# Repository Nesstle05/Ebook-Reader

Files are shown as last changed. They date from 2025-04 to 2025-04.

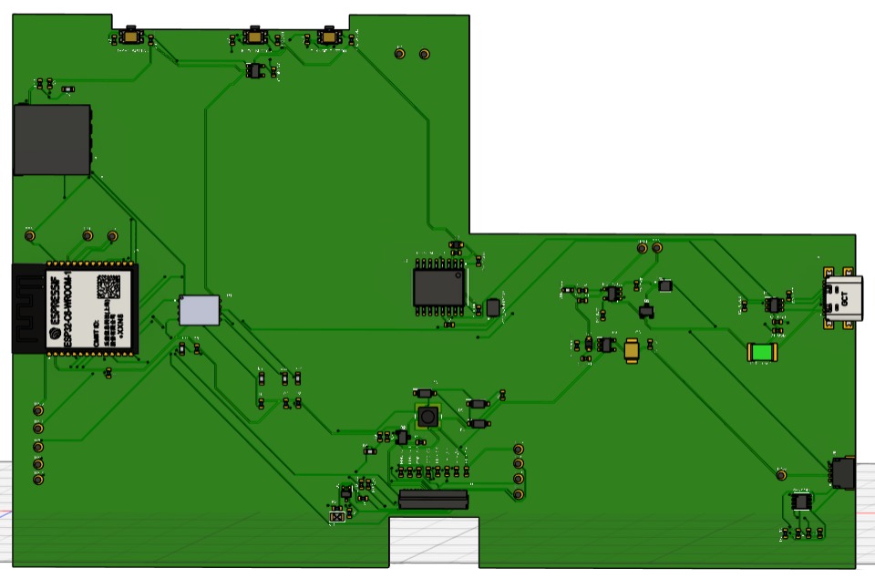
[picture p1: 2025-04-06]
Images/pcb3D.jpg

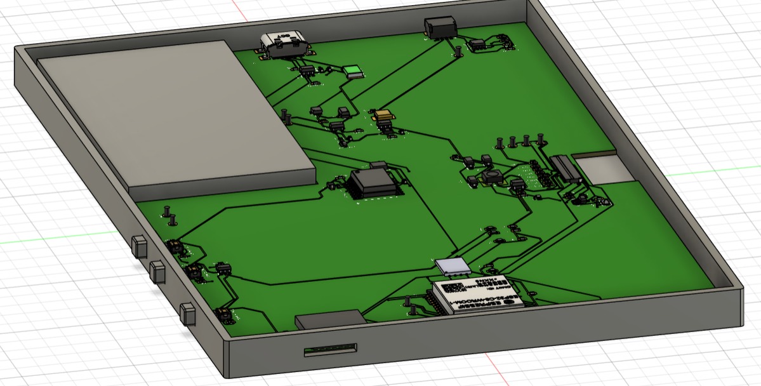
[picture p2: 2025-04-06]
Images/openbook_enclosure2.jpg

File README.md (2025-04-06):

# Ebook-Reader

### Pasii de implementare
* Am creat schematicul 2D.
* Am creat PCB-ul, am intampinat niste erori:
    * **Via(hole) error** la componenta USB: am modificat footprint-ul componentei.
    * **Wire to wire error**: am rutat firele manual
* Am atribuit fiecarei componente din library cate un model 3D, si am creat placa 3d (*Push to 3D*)
* Am creat modelele pentru Display si Baterie dupa specificatiile din datasheeturi

## Diagrama bloc


## Utilizarea Pinilor ESP32-C6

Următorul tabel detaliază pinii GPIO specifici utilizați pe modulul ESP32-C6-WROOM-1 și funcțiile acestora în cadrul acestui proiect:

| Pin ESP32-C6 | Funcție | Component(e) Conectat(e) | Interfață/Motiv |
| :--- | :--- | :--- | :--- |
| GPIO0 | Selecție Boot / Intrare Buton | SW_BOOT (Buton Boot), R_BOOT | Pin standard pentru selecția modului boot; Intrare utilizator |
| GPIO1 | Ceas I2C | U4 (MAX17048), U3 (DS3231), SENSOR2 (BME688), J5 (Qwiic) | Magistrală I2C comună (SCL) pentru multipli senzori/CI |
| GPIO2 | Date I2C | U4 (MAX17048), U3 (DS3231), SENSOR2 (BME688), J5 (Qwiic) | Magistrală I2C comună (SDA) pentru multipli senzori/CI |
| GPIO3 | Selecție Cip E-Paper | J1 (Header EPD) | Selecție Cip SPI (CS) pentru Afișajul E-Paper |
| GPIO4 | Dată/Comandă E-Paper | J1 (Header EPD) | Control Dată/Comandă (DC) pentru Afișajul E-Paper |
| GPIO5 | Reset E-Paper | J1 (Header EPD) | Semnal Reset (RST) pentru Afișajul E-Paper |
| GPIO6 | Stare Ocupat E-Paper | J1 (Header EPD) | Semnal intrare Ocupat (Busy) de la Afișajul E-Paper |
| GPIO7 | Hold Flash Extern | U1 (W25Q64JV), TP17 | Semnal SPI Hold (/HOLD) pentru memoria flash externă |
| GPIO8 | Dată 0 Card SD | J2 (Slot Card SD), TP6 | Linie Date SDIO 0 / SPI MISO |
| GPIO9 | Dată 1 Card SD | J2 (Slot Card SD), TP7 | Linie Date SDIO 1 |
| GPIO10 | Comandă Card SD | J2 (Slot Card SD), TP5 | Linie Comandă SDIO / SPI MOSI |
| GPIO11 | Ceas Card SD | J2 (Slot Card SD), TP4 | Linie Ceas SDIO / SPI SCK |
| GPIO12 | Protecție Scriere Flash Extern | U1 (W25Q64JV), TP16 | Semnal SPI Protecție Scriere (/WP) pentru flash extern |
| GPIO13 | MISO Flash Extern | U1 (W25Q64JV), TP15 | SPI Master In Slave Out (MISO) pentru flash extern |
| GPIO14 | MOSI Flash Extern | U1 (W25Q64JV), TP14 | SPI Master Out Slave In (MOSI) pentru flash extern |
| GPIO15 | Selecție Cip Flash Extern | U1 (W25Q64JV), TP13 | Selecție Cip SPI (/CS) pentru memoria flash externă |
| GPIO16 | UART TXD | TP12 | Date Transmise UART pentru depanare/programare |
| GPIO17 | UART RXD | TP11 | Date Recepționate UART pentru depanare/programare |
| GPIO18 | Ceas Flash Extern | U1 (W25Q64JV), TP3 | Ceas SPI (SCK) pentru memoria flash externă |
| GPIO19 | Dată 2 Card SD | J2 (Slot Card SD), TP8 | Linie Date SDIO 2 |
| GPIO20 | Dată 3 Card SD / Detectare Card | J2 (Slot Card SD), TP9 | Linie Date SDIO 3 / Intrare Detectare Card |
| GPIO21 | Intrare Buton Change | SW_CHANGE (Buton Change) | Intrare de Uz General pentru interacțiune utilizator |
| USB_D- | Date Negative USB | J4 (Conector USB-C) | Semnal Nativ USB D- |
| USB_D+ | Date Pozitive USB | J4 (Conector USB-C) | Semnal Nativ USB D+ |
| EN | Activare Sistem / Reset | U5 (BD5229G), SW_RESET (Buton Reset) | Activare Cip, controlat de supervizor tensiune/buton |

## Energy management

| Component | Power Supply (V) | Estimated Current (mA) | Estimated Power (W) | Notes |
|---|---|---|---|---|
| ESP32-C6-WROOM-1-N8 | 3.3 | 150 (average) | 0.5 | Active mode; varies significantly based on usage. |
| SD Card Module | 3.3 | 10 (average) | 0.033 | Intermittent read/write operations. |
| E-Paper Display | 3.3 | 1(average) | 0.0033 | Power used only during updates, very low average. |
| RTC Module - DS3231SN | 3.3 | 1 | 0.0033 | |
| LiPo Fuel Gauger (MAX17048) | 3.3 | 0.05 | 0.000165 | Very low power consumption. |
| BME688 (Environmental Sensor) | 3.3 | 1 (average) | 0.0033 | Intermittent readings. |
| NORFlash64MB (External Flash)| 3.3 | 2 (average) | 0.0066 | Intermittent read/write operations. |
| LDO Voltage Regulator | 5 (input) / 3.3 (output) | Variable | Variable | Efficiency depends on load; quiescent current is very low. |
| USB-C Connector + ESD | 5 (input) | Variable | Variable | Power depends on charging current; ESD protection negligible. |
| Reset/Boot Buttons | N/A | Negligible | Negligible | |
| **Total (Approximate)** | | 150-200 | **~0.55** | This is a rough estimate; actual power depends on duty cycles and usage. |

## Bill Of Materials (BOM)
| Componenta | Achizitie | Datasheet |
| --- | --- | --- |
| PFMF.050.1 | [Cumpara](https://ro.mouser.com/ProductDetail/Schurter/PFMF.050.2?qs=1auRipcfynCums5v1iucSA%3D%3D) |  [Datasheet](https://ro.mouser.com/datasheet/2/358/typ_PFMF-1275918.pdf) |
| USB4110-GF-A | [Cumpara](https://ro.mouser.com/ProductDetail/GCT/USB4110-GF-A?qs=KUoIvG%2F9IlYiZvIXQjyJeA%3D%3D) | [Datasheet](https://ro.mouser.com/datasheet/2/837/GCT_USB4110_Product_Drawing___20k_cycles-3455479.pdf) |
| USBLC6-2SC6Y | [Cumpara](https://ro.mouser.com/ProductDetail/STMicroelectronics/USBLC6-2SC6Y?qs=gNDSiZmRJS%2FOgDexvXkdow%3D%3D) | [Datasheet](https://ro.mouser.com/datasheet/2/389/usblc6_2sc6y-1852505.pdf) |
| SD0805S020S1R0 | [Cumpara](https://ro.mouser.com/ProductDetail/KYOCERA-AVX/SD0805S020S1R0?qs=jCA%252BPfw4LHbpkAoSnwrdjw%3D%3D) | [Datasheet](https://ro.mouser.com/datasheet/2/40/schottky-3165252.pdf) |
| DMG2305UX-7 | [Cumpara](https://ro.mouser.com/ProductDetail/Diodes-Incorporated/DMG2305UX-7?qs=L1DZKBg7t5F%2FNBHrjfxC%252Bg%3D%3D) | [Datasheet](https://www.diodes.com/assets/Datasheets/DMG2305UX.pdf) |
| XC6220A331MR-G | [Cumpara](https://ro.mouser.com/ProductDetail/Torex-Semiconductor/XC6220A331MR-G?qs=AsjdqWjXhJ8ZSWznL1J0gg%3D%3D) | [Datasheet](https://ro.mouser.com/datasheet/2/760/xc6220-3371556.pdf) |
| Condensator 100 uF TANT | [Cumpara](https://ro.mouser.com/ProductDetail/KYOCERA-AVX/TAJW107M010RNJ?qs=Wtp%252Bf%2FAeVqIH8v1VxV%252B1Rg%3D%3D) | [Datasheet](https://ro.mouser.com/datasheet/2/40/TAJ-3165264.pdf) |
| 112A-TAAR-R03_ATTEND | [Cumpara](https://www.digikey.ro/en/products/detail/attend-technology/112A-TAAR-R03/17633923) | [Datasheet](https://www.attend.com.tw/data/download/file/112A-TAAR-R03_Spec.pdf)
| ESP32-C6-WROOM-1-N8 | [Cumpara](https://ro.mouser.com/ProductDetail/Espressif-Systems/ESP32-C6-WROOM-1-N8?qs=8Wlm6%252BaMh8ST02Gmwp74cw%3D%3D) | [Datasheet](https://ro.mouser.com/datasheet/2/891/Espressif_ESP32_C6_WROOM_1__Datasheet_V0_1_PRELIMI-3239987.pdf) |
| MCP73831 | [Cumpara](https://ro.mouser.com/ProductDetail/Microchip-Technology/MCP73831T-2ACI-OT?qs=yUQqVecv4qvbBQBGbHx0Mw%3D%3D) | [Datasheet](https://ro.mouser.com/datasheet/2/268/MCP73831_Family_Data_Sheet_DS20001984H-3441711.pdf) |
| CHG_LED | [Cumpara](https://store.comet.srl.ro/Catalogue/Product/40478/) | [Datasheet](https://www.snapeda.com/parts/KP-1608SURCK/Kingbright/datasheet/) |
| SI1308EDL-T1-GE3 | [Cumpara](https://ro.mouser.com/ProductDetail/Vishay-Semiconductors/SI1308EDL-T1-GE3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) | [Datasheet](https://www.vishay.com/doc?63399) |
| MBR0530 | [Cumpara](https://ro.mouser.com/ProductDetail/Micro-Commercial-Components-MCC/MBR0530-T?qs=9VyI4qLX4NTSXkb9ynzJnA%3D%3D) | [Datasheet](https://ro.mouser.com/datasheet/2/258/mcc_mbr0520~mbr0560sod123-1179695.pdf) |
| Bobina | [Cumpara](https://ro.mouser.com/ProductDetail/Wurth-Elektronik/744043680?qs=PGXP4M47uW6VkZq%252BkzjrHA%3D%3D) | [Datasheet](https://www.we-online.com/components/products/datasheet/744043680.pdf) |
| FH34SRJ-24S-0.5SH_99_ | [Cumpara](https://ro.mouser.com/ProductDetail/Hirose-Connector/FH34SRJ-24S-0.5SH99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) | [Datasheet](https://ro.mouser.com/datasheet/2/185/FH34SRJ_24S_0_5SH_99__CL0580_1255_6_99_2DDrawing_0-1615044.pdf) |
| BME688 | [Cumpara](https://ro.mouser.com/ProductDetail/Bosch-Sensortec/BME688?qs=IS%252B4QmGtzzqQoVDscqwx3A%3D%3D) | [Datasheet](https://ro.mouser.com/datasheet/2/783/bst_bme688_fl000-2307034.pdf) |
| BD5229G-TR | [Cumpara](https://ro.mouser.com/ProductDetail/ROHM-Semiconductor/BD5229G-TR?qs=4kLU8WoGk0vvnhrrYwdszw%3D%3D) | [Datasheet](https://fscdn.rohm.com/en/products/databook/datasheet/ic/power/voltage_detector/bd52xxg-e.pdf) |
| Buton adaptat | [Cumpara](https://ro.mouser.com/ProductDetail/CK/KMR221GULCLFS?qs=u2NJ%252B70r0goBXaNk7IrU0Q%3D%3D) | [Datasheet](https://www.ckswitches.com/media/1479/kmr2.pdf) |
| MAX17048G+T10 | [Cumpara](https://ro.mouser.com/ProductDetail/Analog-Devices-Maxim-Integrated/MAX17048G%2bT10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) | [Datasheet](https://ro.mouser.com/datasheet/2/609/MAX17048_MAX17049-3469099.pdf) |
| W25Q512JVEIQ | [Cumpara](https://ro.mouser.com/ProductDetail/Winbond/W25Q512JVEIQ?qs=l7cgNqFNU1jw6svr3at6tA%3D%3D) | [Datasheet](https://ro.mouser.com/datasheet/2/949/Winbond_W25Q512JV_Datasheet-3240039.pdf) |
| PGB1010603MR | [Cumpara](https://ro.mouser.com/ProductDetail/Littelfuse/PGB1010603MRHF?qs=KvZd0dN2Zg%2FuIq6icj%252BGKA%3D%3D) | [Datasheet](https://www.littelfuse.com/media?itemid=8a337998-d54d-466b-be4e-dc5bcd1f9321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) |
| QWIIC_RIGHT_ANGLE | [Cumpara](https://ro.mouser.com/ProductDetail/GCT/USB4110-GF-A?qs=KUoIvG%2F9IlYiZvIXQjyJeA%3D%3D) | [Datasheet](https://ro.mouser.com/datasheet/2/837/GCT_USB4110_Product_Drawing___20k_cycles-3455479.pdf) |
| DS3231SN# | [Cumpara](https://ro.mouser.com/ProductDetail/Analog-Devices-Maxim-Integrated/DS3231SN?qs=ffX8NcjNb2RmKAb9wAk9Ug%3D%3D) | [Datasheet](https://ro.mouser.com/datasheet/2/609/DS3231-3421123.pdf) |
| CPH3225A C10_SUPERCAP | [Cumpara](https://ro.mouser.com/ProductDetail/Seiko-Semiconductors/CPH3225A?qs=3etwrb1wR%252BhUOph6lAO7eg%3D%3D) | [Datasheet](https://ro.mouser.com/datasheet/2/360/Seiko_Instruments_MicroBattery_E_20230330_2024Jan_-3561061.pdf) |
| Condensator 100nF | [Cumpara](https://ro.mouser.com/ProductDetail/KYOCERA-AVX/06033G104ZAT2A?qs=NXubJDmysXJMPmHfVo6Z%252BA%3D%3D) | [Datasheet](https://ro.mouser.com/datasheet/2/40/KGM_Y5V-3223189.pdf) |
| Condensator 4.7uF | [Cumpara](https://ro.mouser.com/ProductDetail/KYOCERA-AVX/0402ZD475MAT2A?qs=NBFAU1oqP4W4U2PCPHI0sg%3D%3D) | [Datasheet](https://ro.mouser.com/datasheet/2/40/cx5r_KGM-3223198.pdf) |
| Condensator 10uF | [Cumpara](https://ro.mouser.com/ProductDetail/Samsung-Electro-Mechanics/CL10A106KQ8NNNL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) | [Datasheet](https://ro.mouser.com/datasheet/2/585/MLCC-1837944.pdf) |
| Condensator 1uF/50V | [Cumpara](https://ro.mouser.com/ProductDetail/KYOCERA-AVX/06035D105MAT2A?qs=k4kUdCzLgS5%252BURKe1SOIeQ%3D%3D) | [Datasheet](https://ro.mouser.com/datasheet/2/40/cx5r_KGM-3223198.pdf) |
| Rezistenta 10K | [Cumpara](https://ro.mouser.com/ProductDetail/Vishay-Beyschlag/MCS0402MD1002BE000?qs=17u8i%2FzlE8%2F9BrAaXkMk1w%3D%3D) | [Datasheet](https://www.vishay.com/doc?28952) |
| Rezistenta 200 | [Cumpara](https://ro.mouser.com/ProductDetail/Vishay-Beyschlag/MCS0402MD2000BE100?qs=3SvaY9RawMJNVte4F12%252BZQ%3D%3D) | [Datasheet](https://www.vishay.com/doc?28952) |
| Rezistenta 100K | [Cumpara](https://ro.mouser.com/ProductDetail/Vishay-Beyschlag/MCT0603PD1003DP500?qs=5aG0NVq1C4wWAn8Ei3OpZA%3D%3D) | [Datasheet](https://www.vishay.com/doc?28916) |
| Rezistenta 2.2 | [Cumpara](https://ro.mouser.com/ProductDetail/SEI-Stackpole/RMCF0402FT2R20?qs=IPgv5n7u5QbBgyl0jwhwsA%3D%3D) | [Datasheet](https://ro.mouser.com/datasheet/2/385/SEI_RMCF_RMCP-3077565.pdf) |
| Rezistenta 5K1| [Cumpara](https://www.venkel.com/part/TFCR0603-16W-K-5690FT) | [Datasheet](https://data.venkel.com/documents/tfcr-series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.) |
| Rezistenta 2K | [Cumpara](https://ro.mouser.com/ProductDetail/Vishay-Beyschlag/MCS04020C2001FE000?qs=wTZ%2FFzl837YG0wIkZJJOwQ%3D%3D) | [Datasheet](https://www.vishay.com/doc?28705) |
| Rezistenta 0.47 | [Cumpara](https://ro.mouser.com/ProductDetail/SEI-Stackpole/CSR0402JKR470?qs=IPgv5n7u5QawIB6nBEt8wA%3D%3D) | [Datasheet](https://ro.mouser.com/datasheet/2/385/SEI_CSR_CSRN-3077593.pdf) |
| Rezistenta 15 | [Cumpara](https://ro.mouser.com/ProductDetail/YAGEO/RT0402FRE0715RL?qs=BXCcY9r%252B08DFFpLSkPOIqQ%3D%3D) | [Datasheet](https://ro.mouser.com/datasheet/2/447/PYu_RT_1_to_0_01_RoHS_L_15-3461507.pdf) |

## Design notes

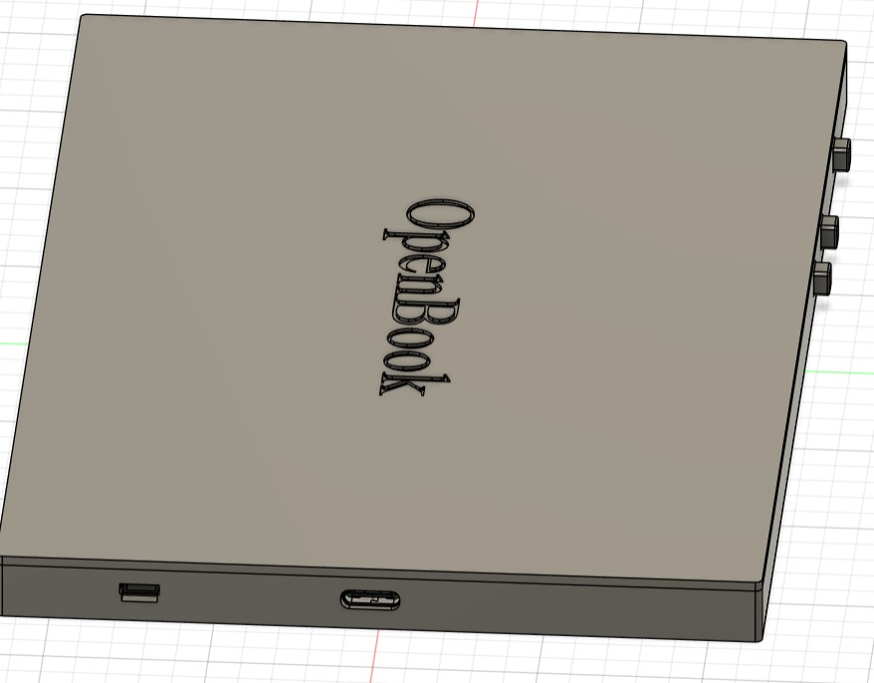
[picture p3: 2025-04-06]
Images/final_look.jpg

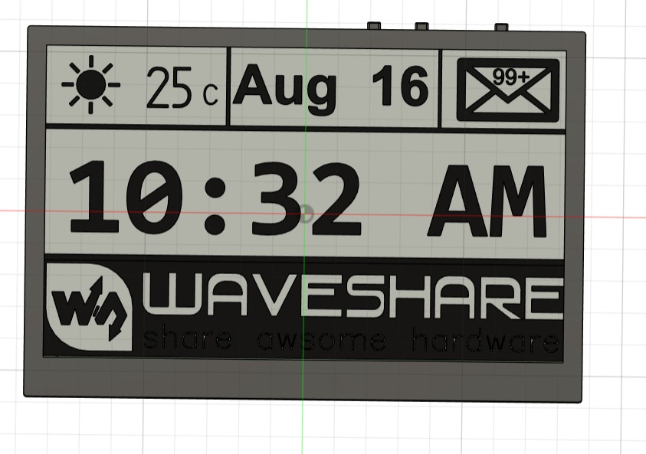
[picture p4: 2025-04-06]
Images/final_look2.jpg

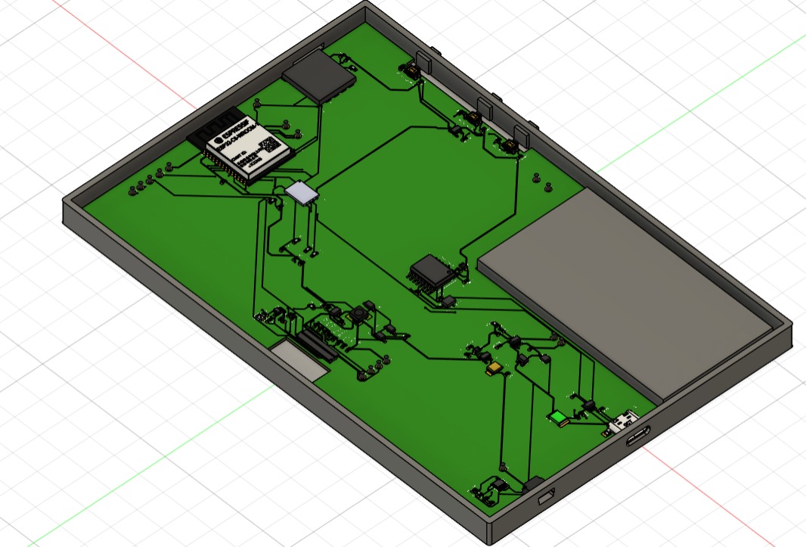
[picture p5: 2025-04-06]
Images/openbook_enclosure.jpg

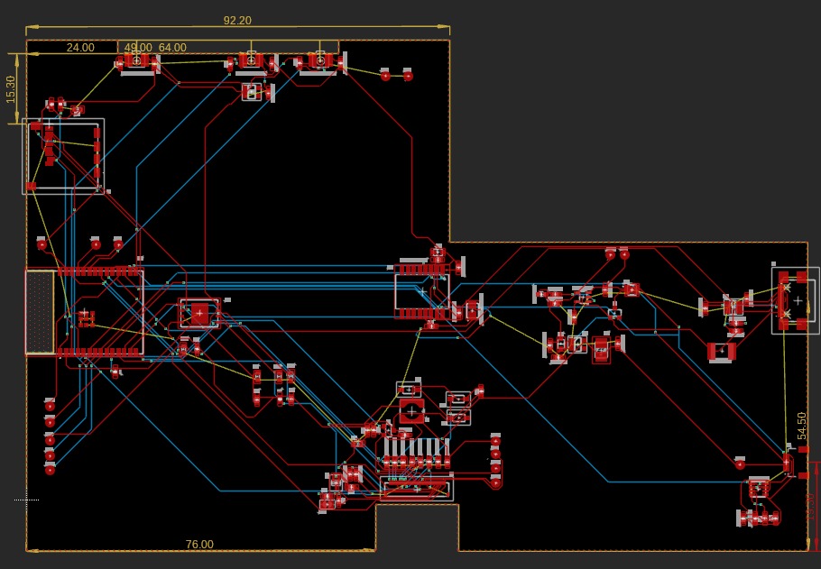
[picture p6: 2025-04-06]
Images/poza1_pcb.jpg

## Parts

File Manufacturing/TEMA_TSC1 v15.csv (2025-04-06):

Qty | Value | Device | Package | Parts | Description | ARROW_PART_NUMBER | ARROW_PRICE-STOCK | AVAILABILITY | CENTROID_NOT_SPECIFIED | CHECK_PRICES | COPYRIGHT | DATASHEET | DESCRIPTION | DIGIKEY_DESCRIPTION | DIGIKEY_PART_NUMBER | HEIGHT | LEAD_FREE | MANUFACTURER_NAME | MANUFACTURER_PART_NUMBER | MF | MFR_NAME | MOUSER_PART_NUMBER | MOUSER_PRICE-STOCK | MOUSER_TESTING_PART_NUMBER | MOUSER_TESTING_PRICE-STOCK | MP | MPN | PACKAGE | POPULARITY | PREFIX | PRICE | PROD_ID | PURCHASE-URL | ROHS | SNAPEDA_LINK | SPICEMODEL | SPICEPREFIX | TEMPERATURE_RANGE_HIGH | TEMPERATURE_RANGE_LOW | TP_SIGNAL_NAME | VALUE
1 |  | ADAFRUIT_LEDCHIP-LED0603 | ADAFRUIT_CHIP-LED0603 | CHG_LED | LED
1 |  | SJ | SJ | SJ1 | SMD solder JUMPER |  |  |  |  |  |  |  |  |  |  |  |  |  |  |  |  |  |  |  |  |  |  |  | 3
1 | 0.1uF/50V | EAGLE-LTSPICE_CC0402 | EAGLE-LTSPICE_C0402 | EPD_C5 | CAPACITOR, European symbol |  |  |  |  |  |  |  |  |  |  |  |  |  |  |  |  |  |  |  |  |  |  |  |  |  |  |  |  |  |  | NONE | C
1 | 0.47 | ESP32_WROVER_EAGLE-LTSPICE_RR0402 | ESP32_WROVER_EAGLE-LTSPICE_R0402 | R3 | RESISTOR, European symbol |  |  |  |  |  |  |  |  |  |  |  |  |  |  |  |  |  |  |  |  |  |  |  |  |  |  |  |  |  |  | NONE | R
1 | 100K | ESP32_WROVER_EAGLE-LTSPICE_RR0402 | ESP32_WROVER_EAGLE-LTSPICE_R0402 | R1_PWRUSB | RESISTOR, European symbol |  |  |  |  |  |  |  |  |  |  |  |  |  |  |  |  |  |  |  |  |  |  |  |  |  |  |  |  |  |  | NONE | R
8 | 100nF | EAGLE-LTSPICE_CC0402 | EAGLE-LTSPICE_C0402 | C1, C2, C4_USB, C6, C8, C9, C10, C_DELAY | CAPACITOR, European symbol |  |  |  |  |  |  |  |  |  |  |  |  |  |  |  |  |  |  |  |  |  |  |  |  |  |  |  |  |  |  | NONE | C
1 | 100uF | RCL_CPOL-EUCT3528 | RCL_CT3528 | C3 | POLARIZED CAPACITOR, European symbol |  |  |  |  |  |  |  |  |  |  |  |  |  |  |  |  |  |  |  |  |  |  |  | 0 |  |  |  |  |  |  |  | C
16 | 10K | ESP32_WROVER_EAGLE-LTSPICE_RR0402 | ESP32_WROVER_EAGLE-LTSPICE_R0402 | R1, R1_PINH, R1_PINH1, R2_PINH, R2_PINH1, R4, R5, R6, R7, R8, R9, R10, R_BOOT, R_CHANGE, R_CL1, R_RESET | RESISTOR, European symbol |  |  |  |  |  |  |  |  |  |  |  |  |  |  |  |  |  |  |  |  |  |  |  |  |  |  |  |  |  |  | NONE | R
1 | 10uF | EAGLE-LTSPICE_CC0402 | EAGLE-LTSPICE_C0402 | C7 | CAPACITOR, European symbol |  |  |  |  |  |  |  |  |  |  |  |  |  |  |  |  |  |  |  |  |  |  |  |  |  |  |  |  |  |  | NONE | C
1 | 112A-TAAR-R03_ATTEND | 112A-TAAR-R03_ATTEND | 112ATAARR03ATTEND | J4 | Micro SD Card Socket, Push-Push Type, Top Mount, SMT, H=1.83mm, 10u |  |  |  |  |  |  |  | Micro SD Card Socket | Push-Push Type | Top Mount | SMT | H=1.83mm | 10u |  |  | 1.9mm |  | ATTEND | 112A-TAAR-R03 ATTEND
1 | 15 | ESP32_WROVER_EAGLE-LTSPICE_RR0402 | ESP32_WROVER_EAGLE-LTSPICE_R0402 | R_CAPACITOR | RESISTOR, European symbol |  |  |  |  |  |  |  |  |  |  |  |  |  |  |  |  |  |  |  |  |  |  |  |  |  |  |  |  |  |  | NONE | R
1 | 1uF | EAGLE-LTSPICE_CC0402 | EAGLE-LTSPICE_C0402 | C5 | CAPACITOR, European symbol |  |  |  |  |  |  |  |  |  |  |  |  |  |  |  |  |  |  |  |  |  |  |  |  |  |  |  |  |  |  | NONE | C
9 | 1uF/50V | EAGLE-LTSPICE_CC0402 | EAGLE-LTSPICE_C0402 | EPD_C1, EPD_C2, EPD_C6, EPD_C7, EPD_C8, EPD_C9, EPD_C10, EPD_C11, EPD_C12 | CAPACITOR, European symbol |  |  |  |  |  |  |  |  |  |  |  |  |  |  |  |  |  |  |  |  |  |  |  |  |  |  |  |  |  |  | NONE | C
1 | 2.2 | ESP32_WROVER_EAGLE-LTSPICE_RR0402 | ESP32_WROVER_EAGLE-LTSPICE_R0402 | R2 | RESISTOR, European symbol |  |  |  |  |  |  |  |  |  |  |  |  |  |  |  |  |  |  |  |  |  |  |  |  |  |  |  |  |  |  | NONE | R
1 | 200 | ESP32_WROVER_EAGLE-LTSPICE_RR0402 | ESP32_WROVER_EAGLE-LTSPICE_R0402 | R1_BAT | RESISTOR, European symbol |  |  |  |  |  |  |  |  |  |  |  |  |  |  |  |  |  |  |  |  |  |  |  |  |  |  |  |  |  |  | NONE | R
2 | 20V/4.2A/52mO/1.4W | ESP32_WROVER_SPARKFUN-DISCRETESEMI_MOSFET_PCH-DMG2305UX-7 | ESP32_WROVER_SPARKFUN-DISCRETESEMI_SOT23-3 | Q1, Q2 | P-channel MOSFETs |  |  |  |  |  |  |  |  |  |  |  |  |  |  |  |  |  |  |  |  |  |  |  |  |  |  | TRAN-14388 |  |  |  |  |  |  |  |  | 20V/4.2A/52mO/1.4W
1 | 2K | ESP32_WROVER_EAGLE-LTSPICE_RR0402 | ESP32_WROVER_EAGLE-LTSPICE_R0402 | R2_BAT | RESISTOR, European symbol |  |  |  |  |  |  |  |  |  |  |  |  |  |  |  |  |  |  |  |  |  |  |  |  |  |  |  |  |  |  | NONE | R
5 | 4.7uF | EAGLE-LTSPICE_CC0402 | EAGLE-LTSPICE_C0402 | C1_BAT, C1_BAT1, C1_BAT2, C2_BAT, C5_USB | CAPACITOR, European symbol |  |  |  |  |  |  |  |  |  |  |  |  |  |  |  |  |  |  |  |  |  |  |  |  |  |  |  |  |  |  | NONE | C
1 | 4.7uF/25V | EAGLE-LTSPICE_CC0402 | EAGLE-LTSPICE_C0402 | C4 | CAPACITOR, European symbol |  |  |  |  |  |  |  |  |  |  |  |  |  |  |  |  |  |  |  |  |  |  |  |  |  |  |  |  |  |  | NONE | C
2 | 5k1 | ESP32_WROVER_EAGLE-LTSPICE_RR0402 | ESP32_WROVER_EAGLE-LTSPICE_R0402 | R2_USB, R2_USB1 | RESISTOR, European symbol |  |  |  |  |  |  |  |  |  |  |  |  |  |  |  |  |  |  |  |  |  |  |  |  |  |  |  |  |  |  | NONE | R
1 | 68uH | 744043680IND_4828-WE-TPC_WRE | IND_4828-WE-TPC_WRE | L1 |  |  |  |  |  |  | Copyright (C) 2024 Ultra Librarian. All rights reserved. |  |  |  |  |  |  |  | 744043680 |  | Wurth Electronics
1 | BD5229G-TR | BD5229G-TR | SOT95P280X125-5N | IC2 | Voltage Detector with Adjustable Delay Time: CMOS processes are utilized to develop high precision, low current consumption CMOS reset ICs that allow arbitrary setting of the delay time. The extensive lineup includes both Nch Open Drain and CMOS output types in a wide range of detection voltages (from 2.3V to 6.0V, in 0.1V steps), enabling selection of the ideal solution based on customer requirements. In addition, the entire series is of course both lead-free and RoHS-compliant. |  |  |  |  |  |  |  | Voltage Detector with Adjustable Delay Time: CMOS processes are utilized to develop high precision | low current consumption CMOS reset ICs that allow arbitrary setting of the delay time. The extensive lineup includes both Nch Open Drain and CMOS output types in a wide range of detection voltages (from 2.3V to 6.0V | in 0.1V steps) | enabling selection of the ideal solution based on customer requirements. In addition | the entire series is of course both lead-free and RoHS-compliant. |  |  | 1.25mm |  | ROHM Semiconductor | BD5229G-TR |  |  | 755-BD5229G-TR | https://www.mouser.co.uk/ProductDetail/ROHM-Semiconductor/BD5229G-TR?qs=4kLU8WoGk0vvnhrrYwdszw%3D%3D
3 | BUTTON_CUSYOMV1 | BUTTON_CUSYOMV1 | MYBUTTON | BOOT_BUTTON, CHANGE_BUTTON, RESET_BUTTON
1 | CPH3225A | CPH3225A | CAPCP3225X100N | C10_SUPERCAP | Cap 0.011F 3.3V 1210 Flat Check availability |  |  | Not in stock |  | https://www.snapeda.com/parts/CPH3225A/Seiko+Instruments/view-part/?ref=eda |  |  | 11 mF (EDLC) Supercapacitor 3.3 V 1210 (3225 Metric) - - |  |  |  |  |  |  | Seiko Instruments |  |  |  |  |  | CPH3225A |  | 1210 Seiko |  |  | None |  | https://www.snapeda.com/api/url_track_click_mouser/?unipart_id=562593&manufacturer=Seiko Instruments&part_name=CPH3225A&search_term=None |  | https://www.snapeda.com/parts/CPH3225A/Seiko+Instruments/view-part/?ref=snap
1 | DS3231SN# | DS3231SN# | SOIC127P1032X265-16N | U3 | Real Time Clock Serial 16-Pin SOIC W T/R Check availability |  |  | In Stock |  | https://www.snapeda.com/parts/DS3231SN%23/Analog+Devices/view-part/?ref=eda |  |  | Extremely Accurate I²C-Integrated RTC/TCXO/Crystal |  |  |  |  |  |  | Analog Devices |  |  |  |  |  | DS3231SN# |  | SOIC-16 Maxim |  |  | None |  | https://www.snapeda.com/api/url_track_click_mouser/?unipart_id=99048&manufacturer=Analog Devices&part_name=DS3231SN#&search_term=None |  | https://www.snapeda.com/parts/DS3231SN%23/Analog+Devices/view-part/?ref=snap
1 | ESP32-C6-WROOM-1-N8 | ESP32-C6-WROOM-1-N8 | XCVR_ESP32-C6-WROOM-1-N8 | U2 | Check availability |  |  | In Stock |  | https://www.snapeda.com/parts/ESP32-C6-WROOM-1-N8/Espressif+Systems/view-part/?ref=eda |  |  | Multiprotocol Modules ESP32-C6 module | Wi-Fi 6 in 2.4 GHz band | Bluetooth 5 | Zigbee 3.0 and Thread. ESP34-WROOM Compatible - ENGINEERING SAMPLE |  |  |  |  |  |  | Espressif Systems |  |  |  |  |  | ESP32-C6-WROOM-1-N8 |  | None |  |  | None |  |  |  | https://www.snapeda.com/parts/ESP32-C6-WROOM-1-N8/Espressif+Systems/view-part/?ref=snap
1 | ESP32C6_VARISTORCN1812 | ESP32C6_VARISTORCN1812 | ESP32C6_VARISTOR_CT/CN1812 | PFMF.050.1 | VARISTOR |  |  |  |  |  |  |  |  |  |  |  |  |  |  |  |  |  |  |  |  |  |  |  | 0
2 | ESP32_WROVER_AVX---SD0805S020S1R0_AVX_SD0805S020S1R0_0_0AVX_SD0805S020S1R0_0_0 | ESP32_WROVER_AVX---SD0805S020S1R0_AVX_SD0805S020S1R0_0_0AVX_SD0805S020S1R0_0_0 | ESP32_WROVER_AVX---SD0805S020S1R0_AVX_SD0805S020S1R0_0 | D2, D7 | Schottky Barrier Rectifier Diode |  |  |  | No |  |  | http://datasheets.avx.com/schottky.pdf |  | DIODE SCHOTTKY 20V 1A 0805 | 478-7800-1-ND |  | yes |  |  | AVX |  | 581-SD0805S020S1R0 |  |  |  |  |  | 0805 (2012 metric) |  | D |  |  |  | yes |  |  |  | +125°C | -55°C
1 | ESP32_WROVER_BME680_BME680 | ESP32_WROVER_BME680_BME680 | ESP32_WROVER_BME680_PSON80P300X300X100-8N | SENSOR2 | Integrated Environmental Unit |  |  | Unavailable |  |  |  |  | Integrated Environmental Unit |  |  |  |  |  |  | Bosch Sensortec |  |  |  |  |  | BME680 |  | LGA-8 Bosch Tools |  |  | None
1 | ESP32_WROVER_SPARKFUN-IC-POWER_MCP73831 | ESP32_WROVER_SPARKFUN-IC-POWER_MCP73831 | ESP32_WROVER_SPARKFUN-IC-POWER_SOT23-5 | MCP73831 | MCP73831T Li-Ion, Li-Pol Controller |  |  |  |  |  |  |  |  |  |  |  |  |  |  |  |  |  |  |  |  |  |  |  |  |  |  | IC-09995
1 | FH34SRJ-24S-0.5SH_99_ | FH34SRJ-24S-0.5SH_99_ | FH34SRJ24S05SH99 | J1 | (0.50mm) Surface Mount, Right Angle |  |  |  |  |  |  |  | 24 Position FFC | FPC Connector Contacts | (0.50mm) Surface Mount | Right Angle |  |  | 1.1mm |  | Hirose | FH34SRJ-24S-0.5SH(99) |  |  | 798-FH34SRJ24S05SH99 | https://www.mouser.co.uk/ProductDetail/Hirose-Connector/FH34SRJ-24S-0.5SH99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
1 | MAX17048G+T10 | MAX17048G+T10 | SON50P200X200X80-9N | U4 | Check availability |  |  | In Stock |  | https://www.snapeda.com/parts/MAX17048G+T10/Analog+Devices/view-part/?ref=eda |  |  | 3µA 1-Cell/2-Cell Fuel Gauge with ModelGauge |  |  |  |  |  |  | Analog Devices |  |  |  |  |  | MAX17048G+T10 |  | TDFN-8 Maxim |  |  | None |  | https://www.snapeda.com/api/url_track_click_mouser/?unipart_id=329239&manufacturer=Analog Devices&part_name=MAX17048G+T10&search_term=None |  | https://www.snapeda.com/parts/MAX17048G+T10/Analog+Devices/view-part/?ref=snap
3 | MBR0530 | MBR0530 | SOD3716X135N | D3, D4, D5 | ON SEMICONDUCTOR - MBR0530 - DIODE, SCHOTTKY, 0.5A, 30V, SOD-123 |  |  | In Stock |  | https://www.snapeda.com/parts/MBR0530/Onsemi/view-part/?ref=eda |  |  | Diode Schottky 30 V 500mA Surface Mount SOD-123 |  |  |  |  |  |  | ON Semiconductor |  |  |  |  |  | MBR0530 |  | SOD-123-2 ON Semiconductor |  |  | None |  | https://www.snapeda.com/api/url_track_click_mouser/?unipart_id=179458&manufacturer=ON Semiconductor&part_name=MBR0530&search_term=None |  | https://www.snapeda.com/parts/MBR0530/Onsemi/view-part/?ref=snap
6 | PGB1010603MR | PGB1010603MR | DIOC1608X36N | D6, D8, D9, D10, D11, D12 | Check availability |  |  | In Stock |  | https://www.snapeda.com/parts/PGB1010603MR/Littelfuse/view-part/?ref=eda |  |  | 150V (Typ) Clamp - Ipp Tvs Diode Surface Mount 0603 (1608 Metric) |  |  |  |  |  |  | Littelfuse Inc. |  |  |  |  |  | PGB1010603MR |  | 0603 Littelfuse Inc. |  |  | None |  | https://www.snapeda.com/api/url_track_click_mouser/?unipart_id=5659453&manufacturer=Littelfuse Inc.&part_name=PGB1010603MR&search_term=None |  | https://www.snapeda.com/parts/PGB1010603MR/Littelfuse/view-part/?ref=snap
1 | QWIIC_RIGHT_ANGLE | QWIIC_CONNECTORJS-1MM | JST04_1MM_RA | J3 | SparkFun I2C Standard Qwiic Connector |  |  |  |  |  |  |  |  |  |  |  |  |  |  |  |  |  |  |  |  |  |  |  |  |  |  | CONN-13694 |  |  |  |  |  |  |  |  | QWIIC_RIGHT_ANGLE
1 | SAMACSYS_PARTS_USB4110-GF-A | SAMACSYS_PARTS_USB4110-GF-A | SAMACSYS_PARTS_USB4110GFA | J2 | CONN USB 2.0 TYPE-C R/A SMT |  |  |  |  |  |  |  | CONN USB 2.0 TYPE-C R/A SMT |  |  | 3.26mm |  | GCT (GLOBAL CONNECTOR TECHNOLOGY) | USB4110-GF-A |  |  | 640-USB4110-GF-A | https://www.mouser.co.uk/ProductDetail/GCT/USB4110-GF-A?qs=KUoIvG%2F9IlYiZvIXQjyJeA%3D%3D
1 | SI1308EDL-T1-GE3 | SI1308EDL-T1-GE3 | SOT65P210X110-3N | Q3 | MOSFET N-Ch 30V 1.5A TrenchFET SC70 Vishay Si1308EDL-T1-GE3 N-channel MOSFET Transistor, 1.5 A, 30 V, 3-Pin SC-70 |  |  | In Stock |  | https://www.snapeda.com/parts/SI1308EDL-T1-GE3/Vishay+Siliconix/view-part/?ref=eda |  |  | Si1308EDL-T1-GE3 N-channel MOSFET Transistor | 1.5 A | 30 V | 3-Pin SC-70 | Siliconix / Vishay SI1308EDL-T1-GE3 |  |  |  |  |  |  | Vishay Siliconix |  |  |  |  |  | SI1308EDL-T1-GE3 |  | SOT-323 Vishay Semiconductor |  |  | None |  | https://www.snapeda.com/api/url_track_click_mouser/?unipart_id=274603&manufacturer=Vishay Siliconix&part_name=SI1308EDL-T1-GE3&search_term=None |  | https://www.snapeda.com/parts/SI1308EDL-T1-GE3/Vishay+Siliconix/view-part/?ref=snap
17 | TPTP20R | TPTP20R | TP20R | TP1, TP2, TP3, TP4, TP5, TP6, TP7, TP8, TP9, TP10, TP11, TP12, TP13, TP14, TP15, TP16, TP17 | Test pad |  |  |  |  |  |  |  |  |  |  |  |  |  |  |  |  |  |  |  |  |  |  |  | 2
1 | USBLC6-2SC6Y | USBLC6-2SC6Y | SOT95P280X145-6N | D1 | Low Cap. ESD Protection Auto SOT-23-6 STMicroelectronics USBLC6-2SC6Y, Dual Uni-Directional TVS Diode Array, 6-Pin SOT-23 |  |  | In Stock |  | https://www.snapeda.com/parts/USBLC6-2SC6Y/STMicroelectronics/view-part/?ref=eda |  |  | 17V Clamp 5A (8/20µs) Ipp Tvs Diode Surface Mount SOT-23-6 |  |  |  |  |  |  | STMicroelectronics |  |  |  |  |  | USBLC6-2SC6Y |  | SOT-23-6 STMicroelectronics |  |  | None |  |  |  | https://www.snapeda.com/parts/USBLC6-2SC6Y/STMicroelectronics/view-part/?ref=snap
1 | W25Q512JVEIQ | W25Q512JVEIQ | SON127P600X800X80-9N | U1 | Check availability |  |  | In Stock |  | https://www.snapeda.com/parts/W25Q512JVEIQ/Winbond+Electronics/view-part/?ref=eda |  |  | FLASH - NOR Memory IC 512Mb (64M x 8) SPI - Quad I/O 133 MHz 8-WSON (8x6) |  |  |  |  |  |  | Winbond Electronics |  |  |  |  |  | W25Q512JVEIQ |  | Package |  |  | None |  |  |  | https://www.snapeda.com/parts/W25Q512JVEIQ/Winbond+Electronics/view-part/?ref=snap
1 | XC6220A331MR-G | XC6220A331MR-G | SOT95P280X120-5N | IC4 | LDO Voltage Regulators |  |  |  |  |  |  |  | LDO Voltage Regulators |  |  | 1.2mm |  | Torex | XC6220A331MR-G |  |  | 865-XC6220A331MR-G | https://www.mouser.co.uk/ProductDetail/Torex-Semiconductor/XC6220A331MR-G?qs=AsjdqWjXhJ8ZSWznL1J0gg%3D%3D

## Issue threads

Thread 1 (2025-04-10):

[PCB] Via Stitching is missing around the ESP32 microcontroller

RockyMaster77, 2025-04-10:
It is recommended to apply via stitching around the ESP32 to connect the 2 GND layers to reduce as much as possible the interference and noise to the antenna.

Closed 2025-04-16.

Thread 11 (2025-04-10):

[SCH] Add separation lines between the components

RockyMaster77, 2025-04-10:
The lines between the components are missing. Also, name the groups (ex: SD Card, EPD Power...).

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

Closed 2025-04-16.

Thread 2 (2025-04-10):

[PCB] DRC errors

RockyMaster77, 2025-04-10:
There are some errors from the DRC with the copper width. Try to reconnect the cables.
Also, fix the board outline clearance problems. Try to pull the components from the exterior of the board a little bit to the interior.

Closed 2025-04-16.

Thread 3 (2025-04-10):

[PCB] Routed differentialy

RockyMaster77, 2025-04-10:
The USB+ and USB- signal cables should be routed parallel as close as possible to avoid noise and signal delays. It is recommended to have aprox. the same length.

Closed 2025-04-16.

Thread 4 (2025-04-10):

[PCB]  Minimize crossing reference plane splits/slots or changing layers

RockyMaster77, 2025-04-10:
In some areas of the board, there is no GND layer. Use Via stitching on those areas to connect at least one GND layer(recommended both - top and bottom as well).

Closed 2025-04-16.

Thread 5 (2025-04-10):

[PCB] Confirm PCB dimensions and mounting hole size/placement against enclosure

RockyMaster77, 2025-04-10:
There are dimension notations missing. Make sure all dimensions are on the dimension layer (20) and are visible and easy to read.

Closed 2025-04-16.

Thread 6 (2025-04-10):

[PCB]  Components not physically overlapping/colliding

RockyMaster77, 2025-04-10:
There is a high chance this component on the 3D model is colliding with the device case. Place it a little bit to the interior.

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

Closed 2025-04-16.

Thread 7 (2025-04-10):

[PCB] Text removed entirely in, or moved outside of, high component/via density areas

RockyMaster77, 2025-04-10:
Where there is no space for silkscreen names, move them to a clear area and connect them with a line to the components for the ease of reading.

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

EX:

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

Closed 2025-04-16.

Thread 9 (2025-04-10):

[PCB] Text size for silkscreen

RockyMaster77, 2025-04-10:
Make the font size bigger and verify the silkscreen is easy to read and visible on the 3D board.

Closed 2025-04-16.

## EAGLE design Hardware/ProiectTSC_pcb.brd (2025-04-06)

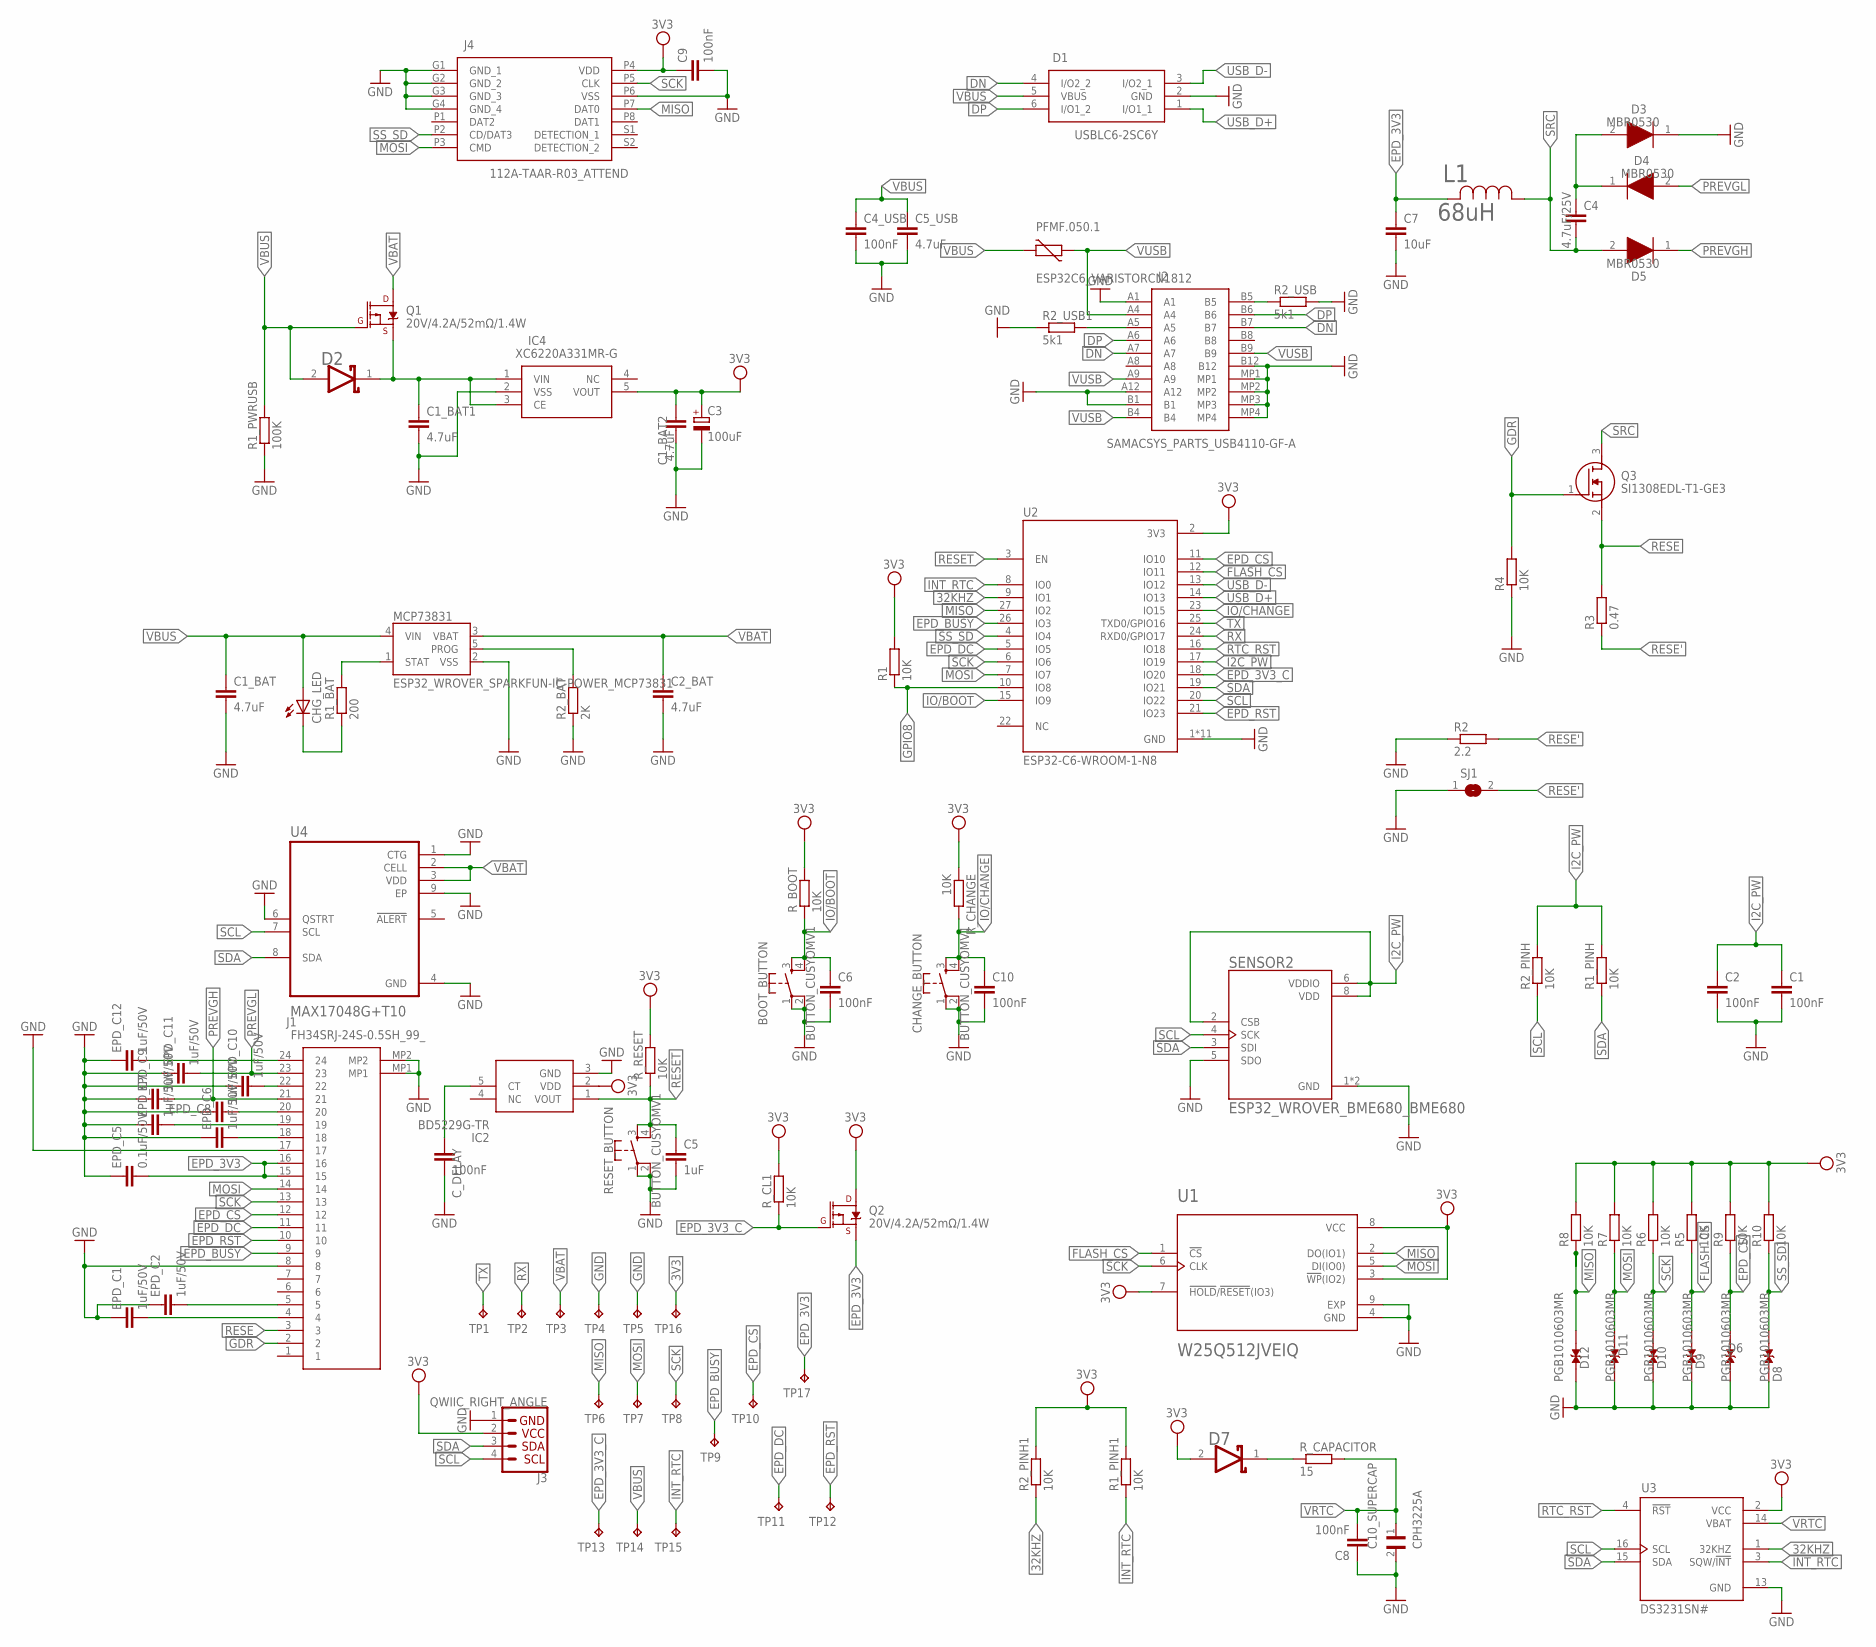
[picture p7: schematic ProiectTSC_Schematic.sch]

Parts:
BOOT_BUTTON: BUTTON_CUSYOMV1; MYBUTTON
C1, C2, C4_USB, C6, C8, C9, C10: 100nF; EAGLE-LTSPICE_C0402
C1_BAT, C1_BAT1, C1_BAT2, C2_BAT, C5_USB: 4.7uF; EAGLE-LTSPICE_C0402
C3: 100uF; RCL_CT3528
C4: 4.7uF/25V; EAGLE-LTSPICE_C0402
C5: 1uF; EAGLE-LTSPICE_C0402
C7: 10uF; EAGLE-LTSPICE_C0402
C10_SUPERCAP: CPH3225A; CAPCP3225X100N
CHANGE_BUTTON: BUTTON_CUSYOMV1; MYBUTTON
CHG_LED: ADAFRUIT_LEDCHIP-LED0603; ADAFRUIT_CHIP-LED0603
C_DELAY: 100nF; EAGLE-LTSPICE_C0402
D1: USBLC6-2SC6Y; SOT95P280X145-6N
D2, D7: ESP32_WROVER_AVX---SD0805S020S1R0_AVX_SD0805S020S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; ESP32_WROVER_AVX---SD0805S020S1R0_AVX_SD0805S020S1R0_0
D3, D4, D5: MBR0530; SOD3716X135N
D6, D8, D9, D10, D11, D12: PGB1010603MR; DIOC1608X36N
EPD_C1, EPD_C2, EPD_C6, EPD_C7, EPD_C8, EPD_C9, EPD_C10, EPD_C11, EPD_C12: 1uF/50V; EAGLE-LTSPICE_C0402
EPD_C5: 0.1uF/50V; EAGLE-LTSPICE_C0402
IC2: BD5229G-TR; SOT95P280X125-5N
IC4: XC6220A331MR-G; SOT95P280X120-5N
J1: FH34SRJ-24S-0.5SH_99_; FH34SRJ24S05SH99
J2: SAMACSYS_PARTS_USB4110-GF-A; SAMACSYS_PARTS_USB4110GFA
J3: QWIIC_RIGHT_ANGLE; JST04_1MM_RA
J4: 112A-TAAR-R03_ATTEND; 112ATAARR03ATTEND
L1: 68uH; IND_4828-WE-TPC_WRE
MCP73831: ESP32_WROVER_SPARKFUN-IC-POWER_MCP73831; ESP32_WROVER_SPARKFUN-IC-POWER_SOT23-5
PFMF.050.1: ESP32C6_VARISTORCN1812; ESP32C6_VARISTOR_CT/CN1812
Q1, Q2: 20V/4.2A/52mΩ/1.4W; ESP32_WROVER_SPARKFUN-DISCRETESEMI_SOT23-3
Q3: SI1308EDL-T1-GE3; SOT65P210X110-3N
R1, R1_PINH, R1_PINH1, R2_PINH, R2_PINH1, R4, R5, R6, R7, R8, R9, R10: 10K; ESP32_WROVER_EAGLE-LTSPICE_R0402
R1_BAT: 200; ESP32_WROVER_EAGLE-LTSPICE_R0402
R1_PWRUSB: 100K; ESP32_WROVER_EAGLE-LTSPICE_R0402
R2: 2.2; ESP32_WROVER_EAGLE-LTSPICE_R0402
R2_BAT: 2K; ESP32_WROVER_EAGLE-LTSPICE_R0402
R2_USB, R2_USB1: 5k1; ESP32_WROVER_EAGLE-LTSPICE_R0402
R3: 0.47; ESP32_WROVER_EAGLE-LTSPICE_R0402
RESET_BUTTON: BUTTON_CUSYOMV1; MYBUTTON
R_BOOT: 10K; ESP32_WROVER_EAGLE-LTSPICE_R0402
R_CAPACITOR: 15; ESP32_WROVER_EAGLE-LTSPICE_R0402
R_CHANGE: 10K; ESP32_WROVER_EAGLE-LTSPICE_R0402
R_CL1: 10K; ESP32_WROVER_EAGLE-LTSPICE_R0402
R_RESET: 10K; ESP32_WROVER_EAGLE-LTSPICE_R0402
SENSOR2: ESP32_WROVER_BME680_BME680; ESP32_WROVER_BME680_PSON80P300X300X100-8N
SJ1: SJ
TP1, TP2, TP3, TP4, TP5, TP6, TP7, TP8, TP9, TP10, TP11, TP12, TP13, TP14, TP15, TP16, TP17: TPTP20R; TP20R
U1: W25Q512JVEIQ; SON127P600X800X80-9N
U2: ESP32-C6-WROOM-1-N8; XCVR_ESP32-C6-WROOM-1-N8
U3: DS3231SN#; SOIC127P1032X265-16N
U4: MAX17048G+T10; SON50P200X200X80-9N

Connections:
3V3: C1_BAT2.1, C3.+, C9.1, D7.2 (ANODE), IC2.2 (VDD), IC4.5 (VOUT), J3.2, J4.P4 (VDD), Q2.3 (D), R1.2, R1_PINH1.2, R2_PINH1.2, R5.2, R6.2, R7.2, R8.2, R9.2, R10.2, R_BOOT.2, R_CHANGE.1, R_CL1.2, R_RESET.2, TP16.TP, U1.3 (!WP!(IO2)), U1.7 (!HOLD!/!RESET!(IO3)), U1.8 (VCC), U2.2 (3V3), U3.2 (VCC)
32KHZ: R2_PINH1.1, U2.9 (IO1), U3.1 (32KHZ)
DN: D1.4 (I/O2_2), J2.A7, J2.B7
DP: D1.6 (I/O1_2), J2.A6, J2.B6
EPD_3V3: C7.1, EPD_C5.2, J1.15, J1.16, L1.2, Q2.2 (S), TP17.TP
EPD_3V3_C: Q2.1 (G), R_CL1.1, TP13.TP, U2.18 (IO20)
EPD_BUSY: J1.9, TP9.TP, U2.26 (IO3)
EPD_CS: D6.2, J1.12, R9.1, TP10.TP, U2.11 (IO10)
EPD_DC: J1.11, TP11.TP, U2.5 (IO5)
EPD_RST: J1.10, TP12.TP, U2.21 (IO23)
FLASH_CS: D9.2, R5.1, U1.1 (!CS), U2.12 (IO11)
GDR: J1.2, Q3.1 (G), R4.2
GND: BOOT_BUTTON.1, BOOT_BUTTON.2, C1.2, C1_BAT.2, C1_BAT1.2, C1_BAT2.2, C2.2, C2_BAT.2, C3.-, C4_USB.2, C5.2, C5_USB.2, C6.2, C7.2, C8.1, C9.2, C10.2, C10_SUPERCAP.2, CHANGE_BUTTON.1, CHANGE_BUTTON.2, C_DELAY.2, D1.2 (GND), D3.1 (K), D6.1, D8.1, D9.1, D10.1, D11.1, D12.1, EPD_C1.1, EPD_C2.1, EPD_C5.1, EPD_C6.1, EPD_C7.1, EPD_C8.1, EPD_C9.1, EPD_C10.1, EPD_C11.1, EPD_C12.1, IC2.3 (GND), IC4.2 (VSS), J1.8, J1.17, J1.MP1, J1.MP2, J2.A1, J2.A12, J2.B1, J2.B12, J2.MP1, J2.MP2, J2.MP3, J2.MP4, J3.1, J4.G1 (GND_1), J4.G2 (GND_2), J4.G3 (GND_3), J4.G4 (GND_4), J4.P6 (VSS), MCP73831.2 (VSS), R1_PWRUSB.1, R2.1, R2_BAT.1, R2_USB.2, R2_USB1.1, R4.1, RESET_BUTTON.1, RESET_BUTTON.2, SENSOR2.1 (GND), SENSOR2.5 (SDO), SENSOR2.7 (GND), SJ1.1, TP4.TP, TP5.TP, U1.4 (GND), U1.9 (EXP), U2.1 (GND), U2.28 (GND), U2.29_1 (GND), U2.29_2 (GND), U2.29_3 (GND), U2.29_4 (GND), U2.29_5 (GND), U2.29_6 (GND), U2.29_7 (GND), U2.29_8 (GND), U2.29_9 (GND), U3.13 (GND), U4.1 (CTG), U4.4 (GND), U4.6 (QSTRT), U4.9 (EP)
GPIO8: R1.1, U2.10 (IO8)
I2C_PW: C1.1, C2.1, R1_PINH.2, R2_PINH.2, SENSOR2.2 (CSB), SENSOR2.6 (VDDIO), SENSOR2.8 (VDD), U2.17 (IO19)
INT_RTC: R1_PINH1.1, TP15.TP, U2.8 (IO0), U3.3 (SQW/!INT)
IO/BOOT: BOOT_BUTTON.3, BOOT_BUTTON.4, C6.1, R_BOOT.1, U2.15 (IO9)
IO/CHANGE: C10.1, CHANGE_BUTTON.3, CHANGE_BUTTON.4, R_CHANGE.2, U2.23 (IO15)
MISO: D12.2, J4.P7 (DAT0), R8.1, TP6.TP, U1.2 (DO(IO1)), U2.27 (IO2)
MOSI: D11.2, J1.14, J4.P3 (CMD), R7.1, TP7.TP, U1.5 (DI(IO0)), U2.7 (IO7)
unnamed: C1_BAT1.1, D2.1 (CATHODE), IC4.1 (VIN), IC4.3 (CE), Q1.2 (S)
unnamed: MCP73831.1 (STAT), R1_BAT.2
unnamed: CHG_LED.C, R1_BAT.1
unnamed: MCP73831.5 (PROG), R2_BAT.2
unnamed: J2.B5, R2_USB.1
unnamed: J2.A5, R2_USB1.2
unnamed: C4.1, D3.2 (A), D4.1 (K)
unnamed: D7.1 (CATHODE), R_CAPACITOR.1
unnamed: C_DELAY.1, IC2.5 (CT)
unnamed: EPD_C12.2, J1.24
unnamed: EPD_C10.2, J1.22
unnamed: EPD_C8.2, J1.20
unnamed: EPD_C7.2, J1.19
unnamed: EPD_C6.2, J1.18
unnamed: EPD_C2.2, J1.5
unnamed: EPD_C1.2, J1.4
PREVGH: D5.1 (K), EPD_C9.2, J1.21
PREVGL: D4.2 (A), EPD_C11.2, J1.23
RESE: J1.3, Q3.2 (S), R3.2
RESE': R2.2, R3.1, SJ1.2
RESET: C5.1, IC2.1 (VOUT), RESET_BUTTON.3, RESET_BUTTON.4, R_RESET.1, U2.3 (EN)
RTC_RST: U2.16 (IO18), U3.4 (!RST)
RX: TP2.TP, U2.24 (RXD0/GPIO17)
SCK: D10.2, J1.13, J4.P5 (CLK), R6.1, TP8.TP, U1.6 (CLK), U2.6 (IO6)
SCL: J3.4, R2_PINH.1, SENSOR2.4 (SCK), U2.20 (IO22), U3.16 (SCL), U4.7 (SCL)
SDA: J3.3, R1_PINH.1, SENSOR2.3 (SDI), U2.19 (IO21), U3.15 (SDA), U4.8 (SDA)
SRC: C4.2, D5.2 (A), L1.1, Q3.3 (D)
SS_SD: D8.2, J4.P2 (CD/DAT3), R10.1, U2.4 (IO4)
TX: TP1.TP, U2.25 (TXD0/GPIO16)
USB_D+: D1.1 (I/O1_1), U2.14 (IO13)
USB_D-: D1.3 (I/O2_1), U2.13 (IO12)
VBAT: C2_BAT.1, MCP73831.3 (VBAT), Q1.3 (D), TP3.TP, U4.2 (CELL), U4.3 (VDD)
VBUS: C1_BAT.1, C4_USB.1, C5_USB.1, CHG_LED.A, D1.5 (VBUS), D2.2 (ANODE), MCP73831.4 (VIN), PFMF.050.1.2, Q1.1 (G), R1_PWRUSB.2, TP14.TP
VRTC: C8.2, C10_SUPERCAP.1, R_CAPACITOR.2, U3.14 (VBAT)
VUSB: J2.A4, J2.A9, J2.B4, J2.B9, PFMF.050.1.1

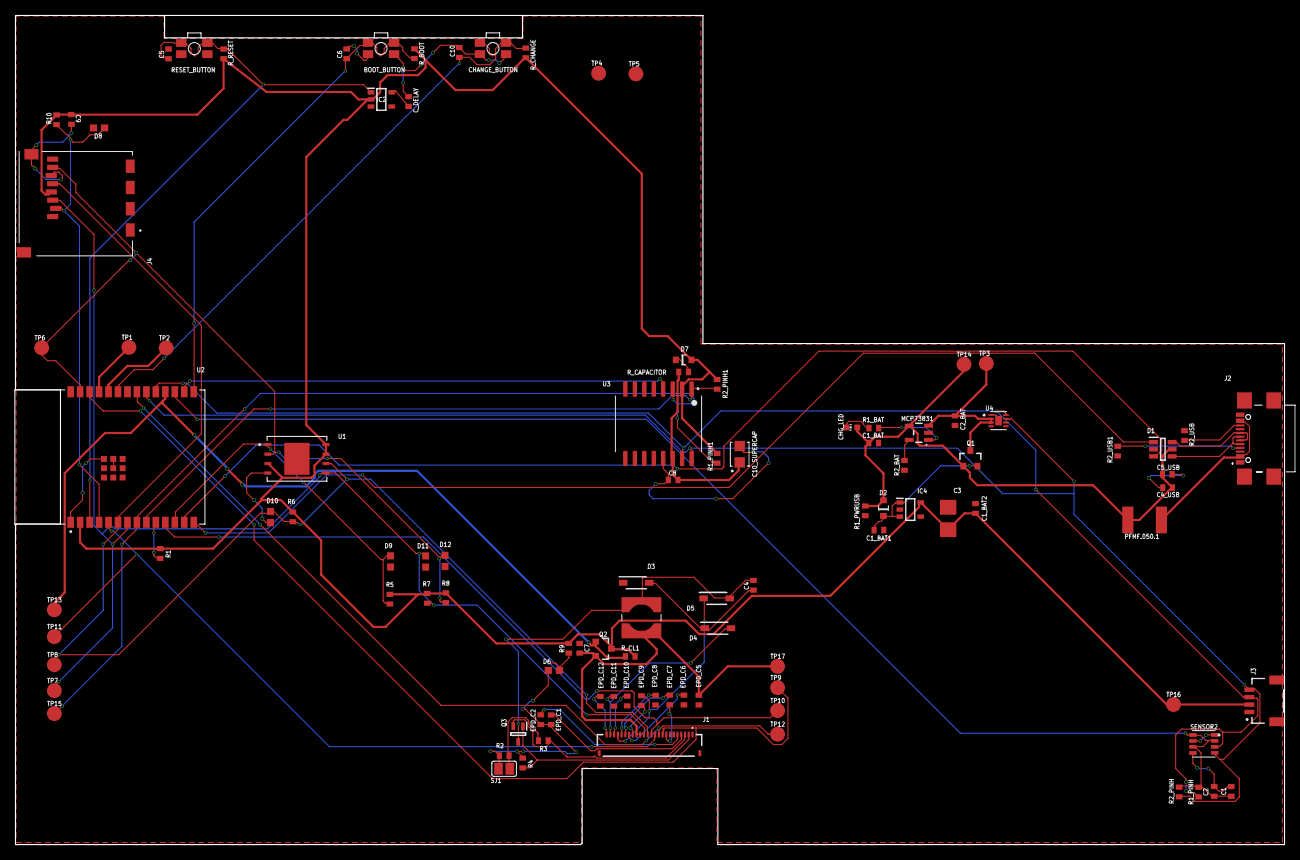
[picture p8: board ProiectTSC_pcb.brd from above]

Board: 2 copper layers, 170.2 x 111.2 mm, 103 parts (0 on the bottom side), 55 nets.

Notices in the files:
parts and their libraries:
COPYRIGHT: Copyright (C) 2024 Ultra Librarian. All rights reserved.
